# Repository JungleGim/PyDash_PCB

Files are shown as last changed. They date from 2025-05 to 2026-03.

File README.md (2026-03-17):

# PyDash_PCB - Information
This readme covers the printed circuit board or PCB portion of the PyDash. For the App design, Enclosure design, or OS design, see the below repositories:
- [PyDash_OS](https://github.com/JungleGim/PyDash_OS)
- [PyDash_App](https://github.com/JungleGim/PyDash_App)
- [PyDash_PCB](https://github.com/JungleGim/PyDash_PCB)
- [PyDash_Enclosure](https://github.com/JungleGim/PyDash_Enclosure)
- [PyDash_Builder](https://github.com/JungleGim/PyDash_Builder)

## Introduction
The PyDash_PCB is a daughter board that contains the hardware required for a rPi compute module (CM4) to function as a processor to display information on a 7in screen.

Additional details on the design considerations, required packages, and key features are included in the "Methodology" section of this readme.

# Project Status
## Revlog
- Rev 0: 06/02/2024
	- Initial issue
- Rev1a: 05/19/2025
	- Fixed button numbering to be appropriate when viewing the screen
- Rev2a: 02/15/2026
	- updates realted to Rev2.0a rebuild - includes new features and code architecture
	- Added micro SD socket for users to load dash config files
	- Updated USB port to USBC
	- Removed touch lines from screen and removed USB mux - no plans to utilize touch in future
	
## Future Development
The below is a list of wants/needs for future revisions; loosely listed in order of importance.

- Update mounting holes for CM4 to solder pads for use of solder-on standoffs to attach CM4
- Scope out board assembly cost

# Methodology
## History
TBD: quick detail starting with the arduino + daughter board on the 5in display as a proof of concept

## Key Considerations and Constraints
The following sections are some notes on the various considerations or any constraints when designing the display.

### Power Supply
As built, with the sourced display and components in the BOM, the display uses approximately 350-400mA when operation, at 100% backlight.

### Display
The chosen display is a 7inch 1024x600 IPS display sourced from waveshare [link](https://www.waveshare.com/70h-1024600.htm?sku=22671). The display is fastened to the carrier PCB via double-sided foam tape. The 40pin FPC jack directly connects to the HDMI output from the CM4.

To control the backlight via PWM, drive the "BL_en" pin high. The PWM signal is scaled from 1024 (100%) to 0 (0) for brightest to darkest.

Any HDMI compatable display should be able to be used with this design. While the FPC cable was a design choice, any other HDMI connection should be appropriate, depending on the chosen display.

Additional considerations for the HDMI hardware and driver configuration is contained in the "PyDash OS" readme.

#### PCB stackup
JLC PCB stackups for TDMS impedence considerations

* Chosen stackup: JLC04121H-3313 – 1oz (0.035mm) outer layer
	+ Chosen stackup option
	+ Top to inner 1 and inner 2 to bot separation is 0.1
	+ requires 0.18mm trace width for single-ended impedence target
	+ 0.3mm separation for differential impedence target

* Other available options with calculated requirements
	+ JLC04121H-7628 - 1oz (0.035mm) outer layer
		* Top to inner 1 and inner 2 to bot separation is 0.2
		* requires 0.3mm trace width for single-ended impedence target
		* 0.25mm separation for differential impedence target
	+ JLC04121H-1080 Stackup – 1oz (0.035mm) outer layer
		* Top to inner 1 and inner 2 to bot separation is 0.0764
		* requires 0.13mm width
		* 0.20mm separation for differential impedence target

# Known bugs and bug fixes
No current known bugs

# FAQ section
No current FAQ

# Copyright and licensing information
## GNU GPLv3
This program is free software: you can redistribute it and/or modify it under the terms of the GNU General Public License as published by the Free Software Foundation, either version 3 of the License, or (at your option) any later version.

This program is distributed in the hope that it will be useful, but WITHOUT ANY WARRANTY; without even the implied warranty of MERCHANTABILITY or FITNESS FOR A PARTICULAR PURPOSE.  See the
GNU General Public License for more details.

You should have received a copy of the GNU General Public License along with this program.  If not, see <https://www.gnu.org/licenses/>.

## Additional disclaimer
The information included is provided "as is", without warranty of any kind, express or implied, including but not limited to the warranties of merchantability, fitness for a particular purpose and non-infringement. In no event shall the authors or copyright holders be liable for any claim, damages or other liability, whether in an action of contract, tort or otherwise, arising from, out of or in connection with the software or the use or other dealings in the software or tools included in this repository.

# General Notes and References
While I am an engineer by trade, my area of focus is not computer architecture or system engineering. Likely some people have already looked at various aspects of the codebase and just shook their heads. That being said, I've compiled a list of considerations and notes for the project that have helped me along the way. These are listed below, in no particular order.

## References
Throughout the project, I have used many references, related to various aspects/items of the project. These are all compiled in the list below, in no particular order
- TBD any notable references

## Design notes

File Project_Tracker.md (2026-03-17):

# PyDash PCB - Project Tracker
project tracker for WIP issues, what's currently being worked on, and anything that may need to move to the actual README file

## Version
Version: 2.0a - TBD
Build Date: N/A

# WIP Version TODO list
* Test complete R2.0a assembly on bench with breakout board
* If successful, order/final assembly
	- Order PCB
	- Order Parts
	- Assemble

# Future Updates
Include any items below in the appropriate README.md file section
(none)

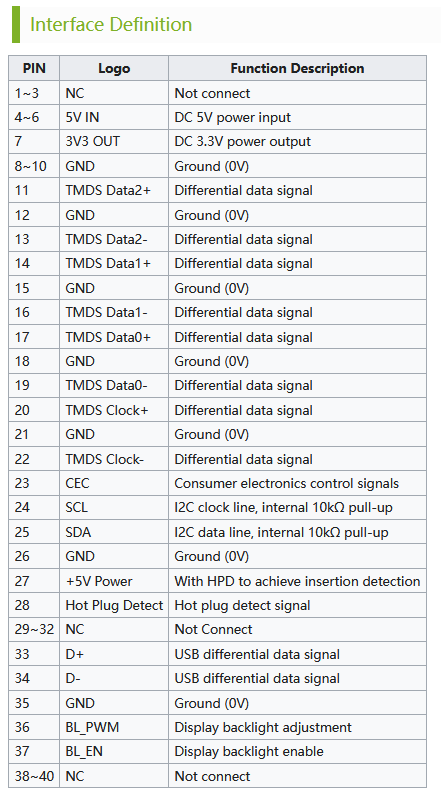
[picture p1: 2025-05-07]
design_and_ref_docs/waveshare_display/40pin_pinout.png

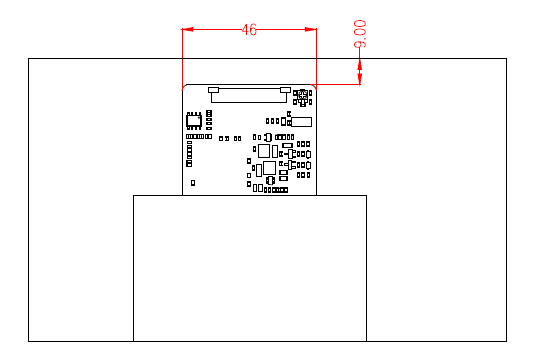
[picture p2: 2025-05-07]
design_and_ref_docs/waveshare_display/waveshare_display_back_dims.png

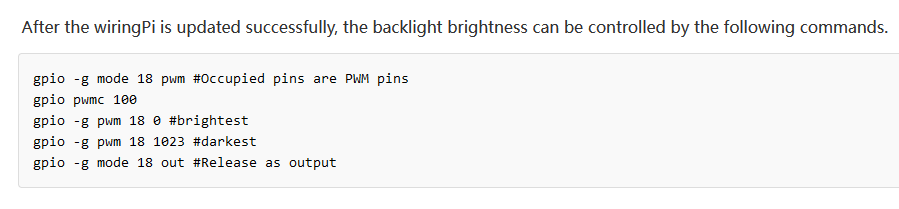
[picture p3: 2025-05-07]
design_and_ref_docs/waveshare_display/PWM_control.png

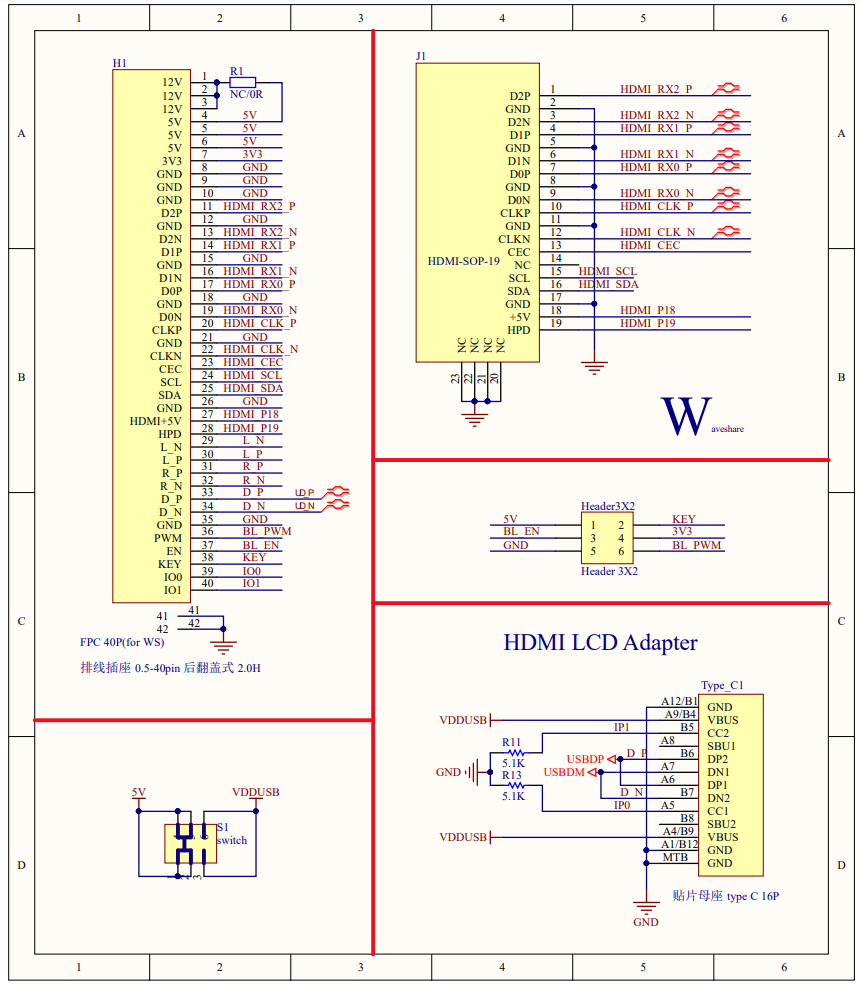
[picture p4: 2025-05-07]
design_and_ref_docs/waveshare_display/waveshare_40pin_hdmi_adapter_schema.png

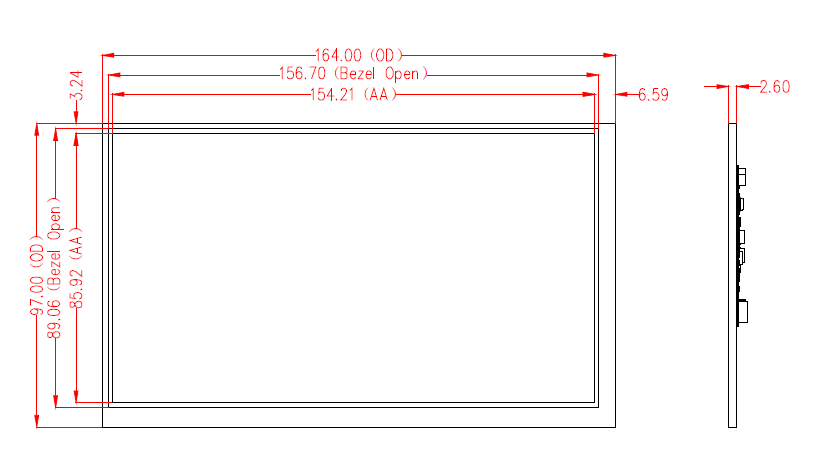
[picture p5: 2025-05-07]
design_and_ref_docs/waveshare_display/waveshare_display_dims.png

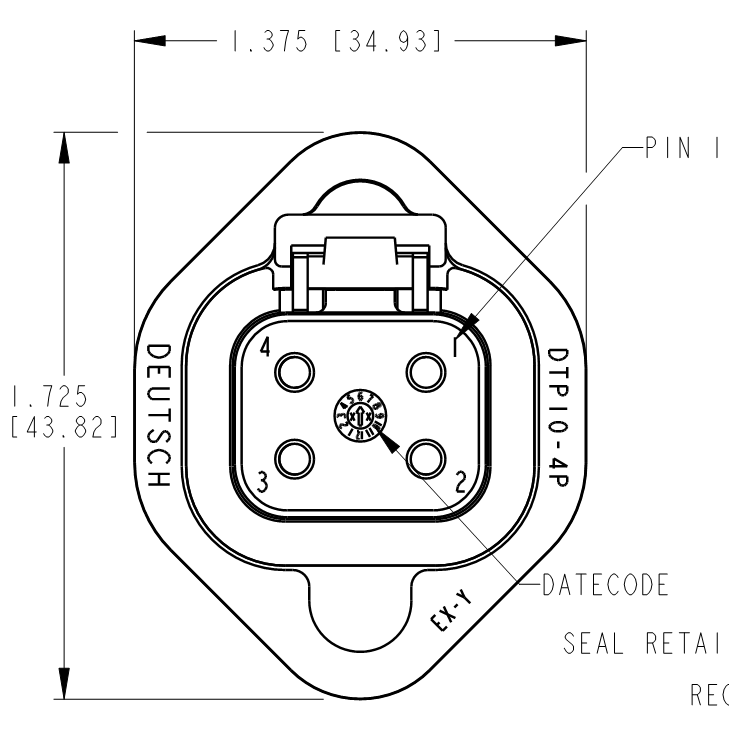
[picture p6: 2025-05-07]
design_and_ref_docs/dt10-40_top.png

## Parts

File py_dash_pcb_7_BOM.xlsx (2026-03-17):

 |  |  |  |  |  |  |  |  | BOM cost: | $158.13
Reference | Value | Footprint | Qty | Source/Reseller | Reseller_P/N | MFGR | MFGR_P/N | qty_check : 3/15/26 | price : 3/15/26 | Line_price
C1,C6,C19,C20,C26,C27,C28,C29,C30,C31 | 1u | Capacitor_SMD:C_0805_2012Metric | 10 | Mouser | 80-C0805C105M3R | Kemet | C0805C105M3RACTU | ok - 4k | $0.17 | $1.70
C18 | 100u | Capacitor_Tantalum_SMD:CP_EIA-3528-21_Kemet-B | 1 | Mouser | 581-TPSB107K010R0400 | Kyocera | TPSB107K010R0400 | ok - 10k | $0.90 | $0.90
C2,C5,C21,C22 | 10u_25v | Capacitor_Tantalum_SMD:CP_EIA-3528-21_Kemet-B | 4 | Mouser | 80-T495B106K25ATE750 | Kemet | T495B106K025ATE750 | ok - 5k | $1.50 | $6.00
C3,C4,C23,C25,C32 | 0u1 | Capacitor_SMD:C_0805_2012Metric | 5 | Mouser | 80-C0805C104M5R | Kemet | C0805C104M5RACTU | ok - 560k | $0.10 | $0.50
C33,C34 | 20p | Capacitor_SMD:C_0805_2012Metric | 2 | Mouser | 80-C0805C200F5G | Kemet | C0805C200F5GACTU | ok - 5k | $1.17 | $2.34
C7 | 1n2 | Capacitor_SMD:C_0805_2012Metric | 1 | Mouser | 80-C0805C122K5R | Kemet | C0805C122K5RACTU | ok - 8k | $0.19 | $0.19
C8,C9,C10,C11,C12,C13,C14,C15,C16,C17,C24 | 10u | Capacitor_SMD:C_0805_2012Metric | 11 | Mouser | 80-C0805C106K4PAC | Kemet | C0805C106K4PAC | ok - 17k | $0.17 | $1.87
D1,D6,D7,D8 | red | LED_SMD:LED_0805_2012Metric | 4 | Mouser | 710-150080RS75000 | Wurth | 150080RS75000 | ok - 65k | $0.19 | $0.76
D2,D3,D4,D5 | 27V | Diode_SMD:D_SOD-123 | 4 | Mouser | 863-MMSZ27T1G | OnSemi | MMSZ27T1G | ok - 23k | $0.12 | $0.48
D9 | NUP2105L | Package_TO_SOT_SMD:SOT-23 | 1 | Mouser | 863-NUP2105LT1G | OnSemi | NUP2105LT1G | ok - 91k | $0.34 | $0.34
H2,H4,H7,He1 | CM4_M2_1.5ET | MountingHole:MountingHole_3.2mm_M3_DIN965_Pad_TopOnly | 4 | Mouser | 710-9774015243R | Wurth | 9774015243R | ok - 20k | $1.16 | $4.64
H8,H9,H10,H11,H12,H13,H14,H15,H16,H17,H18,H19,H20,H21,H22,H23 | Standoff_M2.5_6ET | user:Standoff_M2.5_6ET | 16 | Mouser | 153-SMTSO-M25-6ET | PEM | SMTSO-M25-6ET | ok - 8k | $1.24 | $19.84
J1 | Micro_SD_Card_Det1 | Connector_Card:microSD_HC_Hirose_DM3AT-SF-PEJM5 | 1 | Mouser | 798-DM3ATSFPEJM541 | Hirose | DM3AT-SF-PEJM5(41) | ok - 18k | $3.38 | $3.38
J2 | FFC2B28-40-G | user:GCT_FFC2B28-40-G | 1 | Mouser | 640-FFC2B28-40-G | GCT | FFC2B28-40-G | ok - 6k | $1.00 | $1.00
J3 | USB_C_Receptacle_USB2.0_14P | Connector_USB:USB_C_Receptacle_GCT_USB4115-03-C | 1 | Mouser | 640-USB4115-03-C | GCT | USB4115-03-C | ok - 27k | $1.13 | $1.13
J4 | CANbus | user:DT13-4P | 1 | Mouser | 571-DTP10-4P | Deutsch | DTP10-4P | ok - 120 | $18.35 | $18.35
J5 | CM4-A | N/A | 1 | Mouser | 798-DF40C100DS0.4V51 | Hirose | DF40C-100DS-0.4V(51) | ok - 37k | $1.76 | $1.76
J6 | CM4-B | N/A | 1 | Mouser | 798-DF40C100DS0.4V51 | Hirose | DF40C-100DS-0.4V(51) | ok - 37k | $1.76 | $1.76
J7 | HDMI_ribbon | N/A | 1 | Mouser | 640-0540D0152A4064G | GCT | 05-40-D-0152-A-4-06-4-G | ok - 500 | $2.10 | $2.10
J8 | HDMI_Display | N/A | 1 | Waveshare | 70H-1024600-IPS-A | Waveshare | 70H-1024600-IPS-A | ok | $30.00 | $30.00
J9, J10, J11, J12, J13, J14, J15 | 12x12 keycap - white |  | 6 | Mouser | 653-B32-1360 | Omron | B32-1360 | ok - 5k | $0.20 | $1.20
L1 | 3h3 | Inductor_SMD:L_Bourns_SRN6045TA | 1 | Mouser | 652-SRN6045-3R3Y | Bourns | SRN6045-3R3Y | ok - 20k | $0.42 | $0.42
Q1,Q2,Q3 | DMG2307 | Package_TO_SOT_SMD:SOT-23 | 3 | Mouser | 621-DMG2307L-7 | Diodes | DMG2307L-7 | ok - 53k | $0.42 | $1.26
R1,R12 | 660r | Resistor_SMD:R_0805_2012Metric | 2 | Mouser | 71-CRCW0805-665-E3 | Vishay | CRCW0805665RFKEA | ok - 102k | $0.10 | $0.20
R10 | 2k7 | Resistor_SMD:R_0805_2012Metric | 1 | Mouser | 71-CRCW0805-2.7K-E3 | Vishay | CRCW08052K70FKEA | ok - 25k | $0.19 | $0.19
R11 | 1k | Resistor_SMD:R_0805_2012Metric | 1 | Mouser | 71-CRCW0805-1.0K-E3 | Vishay | CRCW08051K00FKEA | ok - 604k | $0.10 | $0.10
R15,R16,R19,R20,R24,R25 | 27k | Resistor_SMD:R_0805_2012Metric | 6 | Mouser | 71-CRCW0805-27K-E3 | Vishay | CRCW080527K0FKEA | ok - 52k | $0.12 | $0.72
R2 | 10r | Resistor_SMD:R_0805_2012Metric | 1 | Mouser | 71-CRCW0805-10-E3 | Vishay | CRCW080510R0FKEA | ok - 176k | $0.10 | $0.10
R26 | 4k7 | Resistor_SMD:R_0805_2012Metric | 1 | Mouser | 71-CRCW0805-4.7K-E3 | Vishay | CRCW08054K70FKEA | ok - 224k | $0.10 | $0.10
R3 | 12k 1% | Resistor_SMD:R_0805_2012Metric | 1 | Mouser | 71-CRCW0805-12K | Vishay | CRCW080512K0FKTA | ok - 7k | $0.15 | $0.15
R4,R7,R8,R9,R13,R14,R17,R18,R21,R22,R23 | 10k | Resistor_SMD:R_0805_2012Metric | 11 | Mouser | 71-CRCW0805-10K-E3 | Vishay | CRCW080510K0FKEA | ok - 685k | $0.10 | $1.10
R5 | 20k 1% | Resistor_SMD:R_0805_2012Metric | 1 | Mouser | 71-CRCW0805-20K-E3 | Vishay | CRCW080520K0FKEA | ok - 17 | $0.10 | $0.10
R6 | 2k2 1% | Resistor_SMD:R_0805_2012Metric | 1 | Mouser | 71-CRCW0805-2.2K-E3 | Vishay | CRCW08052K20FKEA | ok - 90k | $0.12 | $0.12
SW1 | nBoot | Button_Switch_SMD:SW_DIP_SPSTx01_Slide_6.7x4.1mm_W8.61mm_P2.54mm_LowProfile | 1 | Mouser | 774-219G-2ESF | CTS | 219G-2ESF | ok - 2k | $0.86 | $0.86
SW2,SW3,SW4,SW5,SW6,SW7 | SW_Push | user:SW_B3F-4050_OMR | 6 | Mouser | 653-B3F-5050 | Omron | B3F-5050 | ok - 6k | $0.34 | $2.04
U1 | CM4102008 | user:MODULE_CM4102008 | 1 | Digikey | 2648-SC0696-ND | Raspberry PI | CM4001008 | ok - 400 | $35.00 | $35.00
U2 | AP64501SP-13 | user:SOIC127P600X170-9N | 1 | Mouser | 621-AP64501SP-13 | Diodes | AP64501SP-13 | ok - 15k | $2.09 | $2.09
U3 | BD33FC0FP | Package_TO_SOT_SMD:TO-252-2 | 1 | Mouser | 863-NCV1117DT33T5G | OnSemi | NCV1117DT33T5G | ok - 13k | $0.60 | $0.60
U4 | EMIF06-MSD02N16 | user:EMIF06MSD02N16 | 1 | Mouser | 511-EMIF06-MSD02N16 | ST | EMIF06-MSD02N16 | ok - 7k | $1.03 | $1.03
U5,U6 | TPD8S009DSMR | user:IC_TPD8S009DSMR | 2 | Mouser | 595-TPD8S009DSMR | TI | TPD8S009DSMR | ok - 950 | $1.82 | $3.64
U7 | TPD2EUSB30 | Package_TO_SOT_SMD:Texas_DRT-3 | 1 | Mouser | 595-TPD2E009DRTR | TI | TPD2E009DRTR | ok - 4k | $0.81 | $0.81
U8 | MCP2515-xST | Package_SO:TSSOP-20_4.4x6.5mm_P0.65mm | 1 | Mouser | 579-MCP2515T-E/ST | Microchip | MCP2515T-E/ST | ok - 2k | $3.05 | $3.05
U9 | SN65HVD234 | Package_SO:SOIC-8_3.9x4.9mm_P1.27mm | 1 | Mouser | 595-SN65HVD234DR | TI | SN65HVD234DR | ok - 78k | $3.12 | $3.12
Y1 | 16Mhz | Crystal:Crystal_SMD_3225-4Pin_3.2x2.5mm | 1 | Mouser | 732-FA-23816B-C3 | Epson | FA-238 16.0000MB-C3 | ok - 39k | $1.09 | $1.09

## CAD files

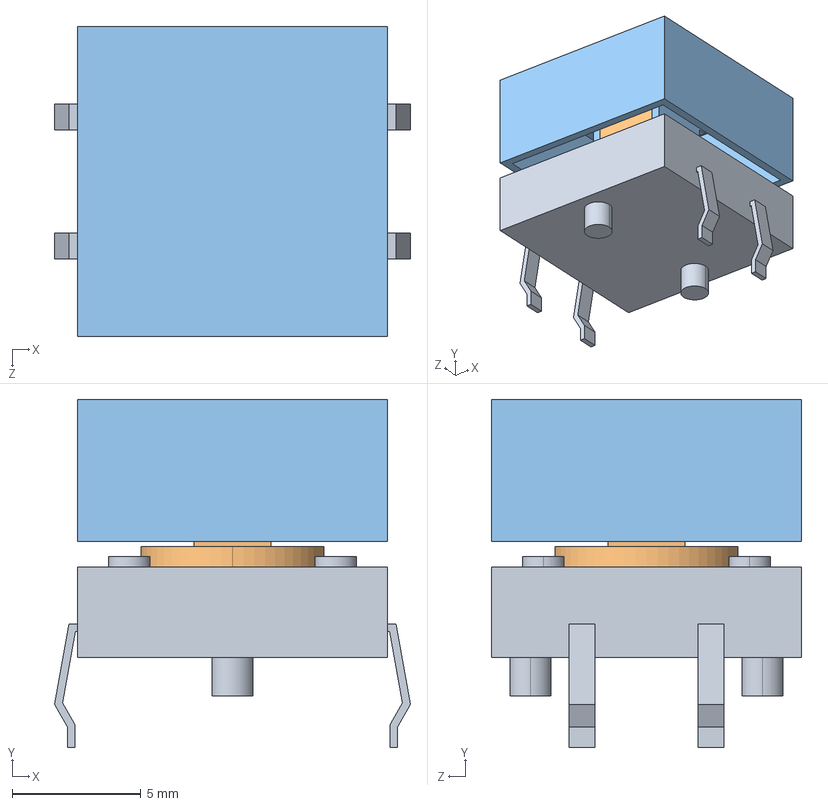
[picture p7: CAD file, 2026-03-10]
PCB_files/user_lib/B3F_5050/B3F-5050_12mm_keycap.STEP
13.8 x 13.5 x 12.0 mm
B3F_5050_BASE_3_B3F_5050_BASE_3
B3F_5050_BUTTON_3_B3F_5050_BUTTON_3
12mm_keycap

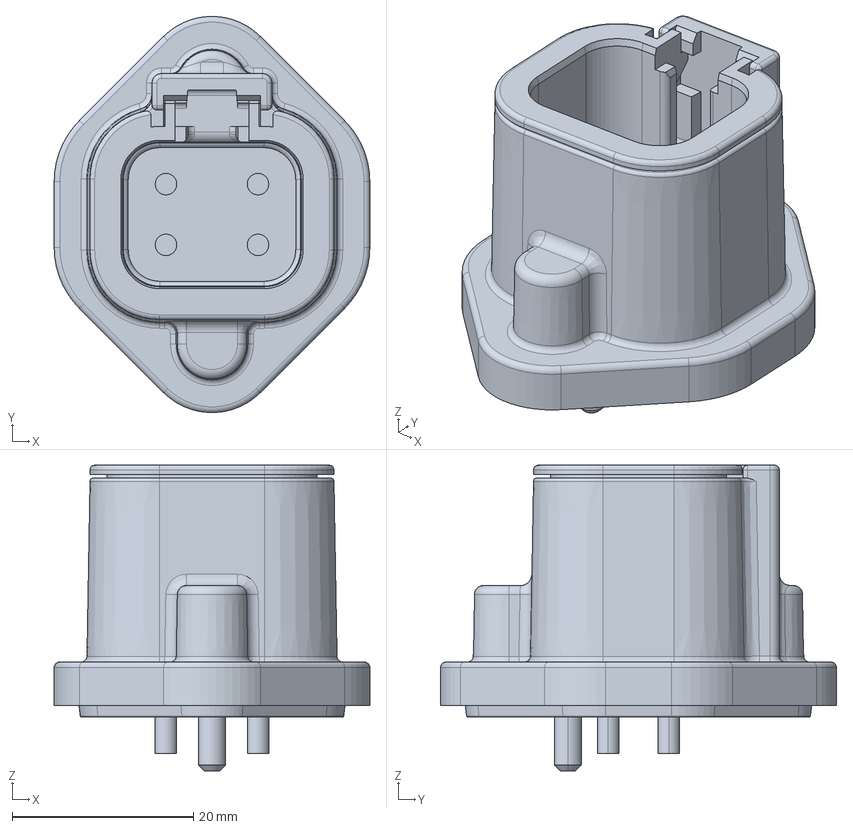
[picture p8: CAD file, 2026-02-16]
PCB_files/user_lib/dt13-4p/c-dtp10-4p-b-3d.stp
34.8 x 43.7 x 33.7 mm

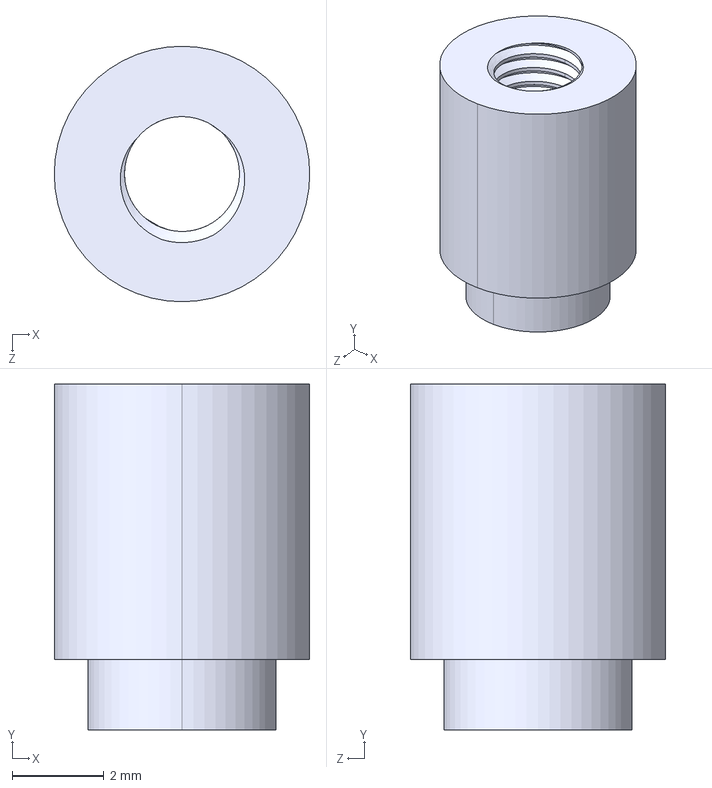
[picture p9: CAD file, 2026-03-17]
PCB_files/user_lib/M2.5_6mm_standoff.STEP
5.56 x 7.53 x 5.56 mm

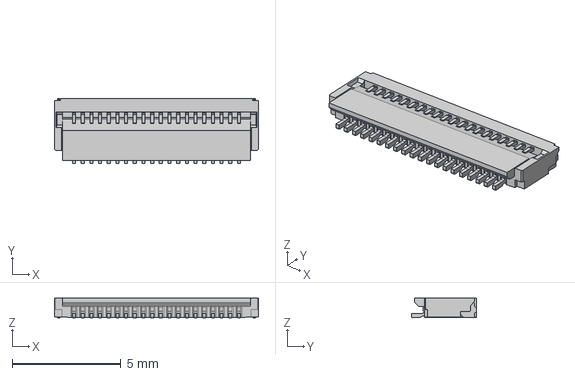
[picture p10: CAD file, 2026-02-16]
PCB_files/user_lib/TF13BSA-20S-0.4SH_800_/TF13BSA-20S-0.4SH_800_.step
9.40 x 3.00 x 0.9 mm

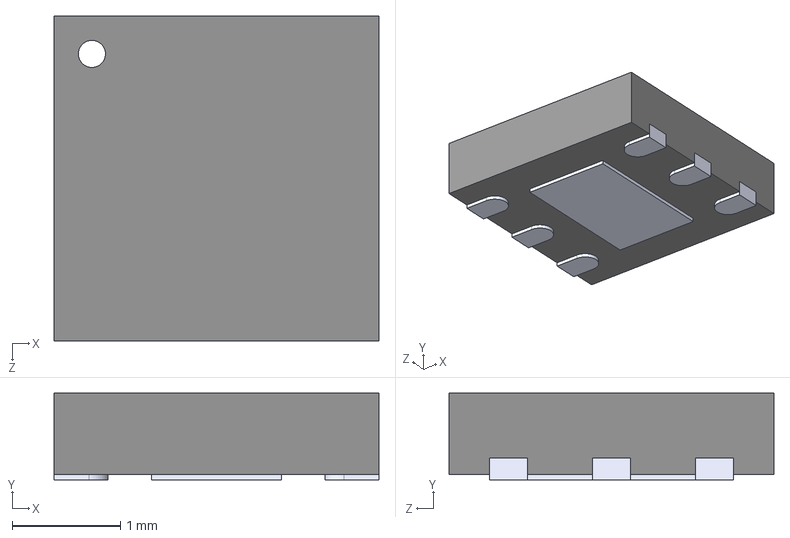
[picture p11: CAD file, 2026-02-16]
PCB_files/user_lib/TPD4E001DRSR_/TPD4E001DRSR..step
3.00 x 0.8 x 3.00 mm

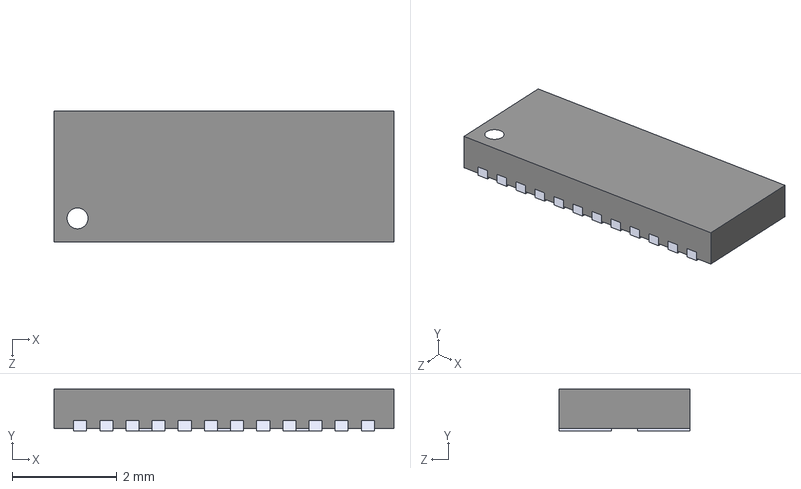
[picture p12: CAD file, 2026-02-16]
PCB_files/user_lib/TPD8S009DSMR/TPD8S009DSMR.step
6.50 x 0.8 x 2.50 mm

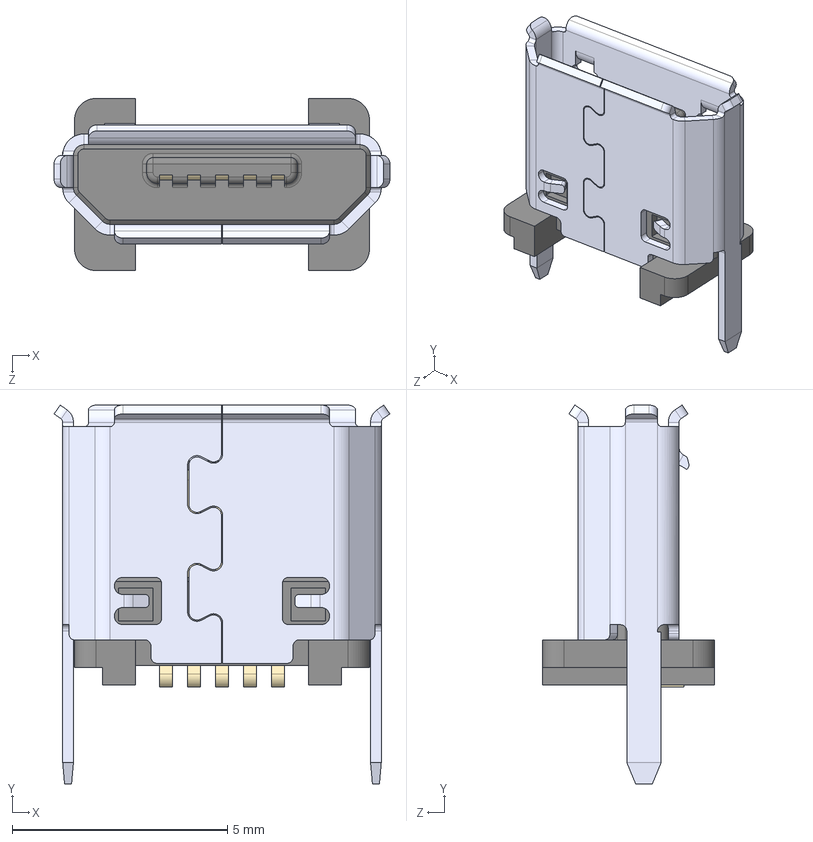
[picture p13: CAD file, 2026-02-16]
PCB_files/user_lib/USB3140-30-0170-1-C_REVE1/USB3140-30-0230-1-C--3DModel-STEP-56544.STEP
7.80 x 8.80 x 4.00 mm

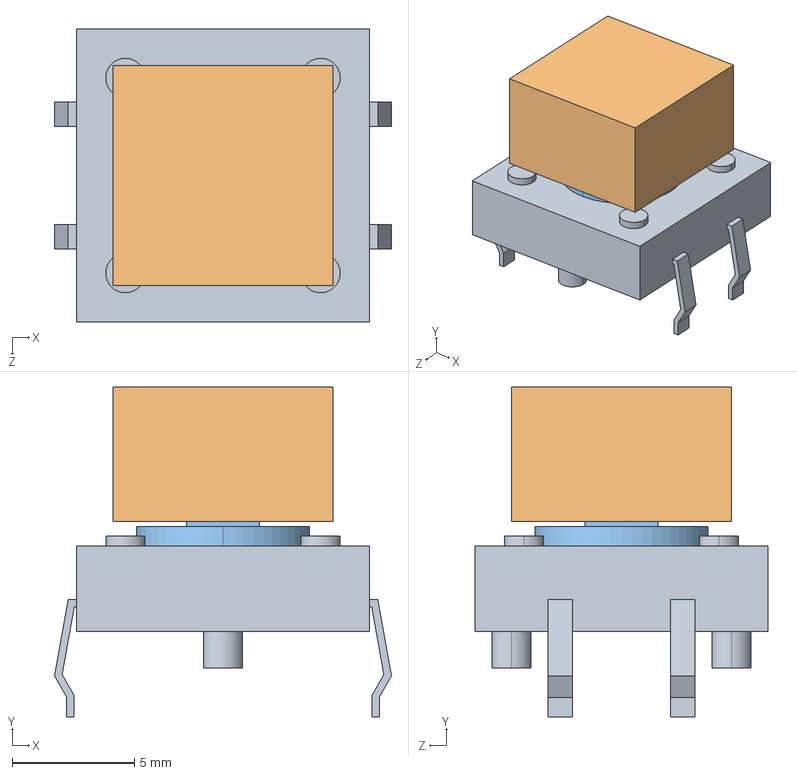
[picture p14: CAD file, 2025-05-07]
PCB_files/user_lib/B3F_5050/B3F-5050.STEP
13.8 x 13.5 x 12.0 mm
B3F_5050_BASE
B32_1200
B3F_5050_BUTTON

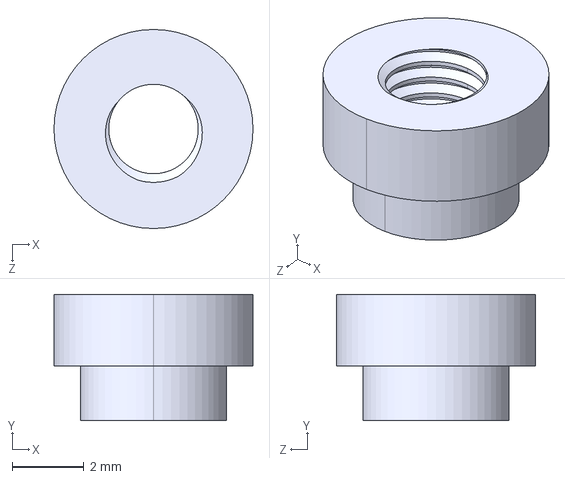
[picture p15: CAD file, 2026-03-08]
PCB_files/user_lib/M2.5_2mm_standoff.STEP
5.56 x 3.53 x 5.56 mm

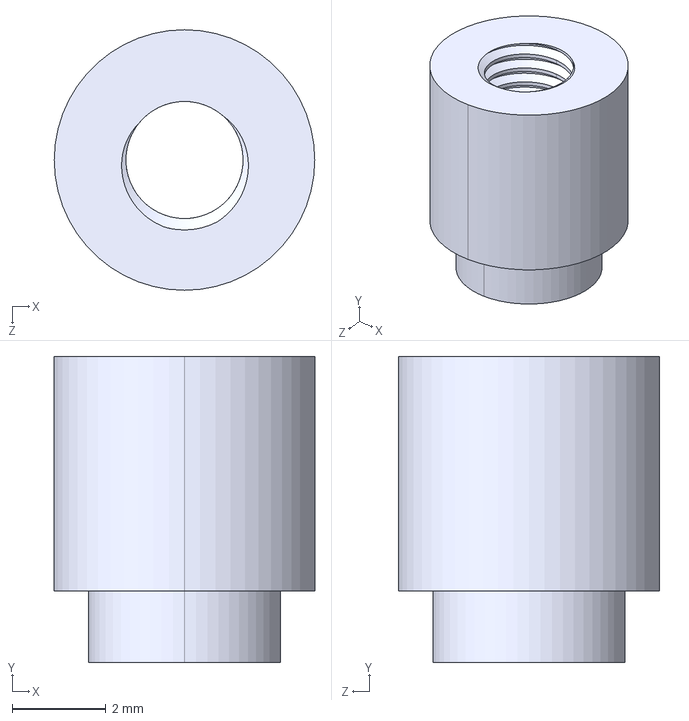
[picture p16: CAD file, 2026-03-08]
PCB_files/user_lib/M2.5_5mm_standoff.STEP
5.56 x 6.53 x 5.56 mm

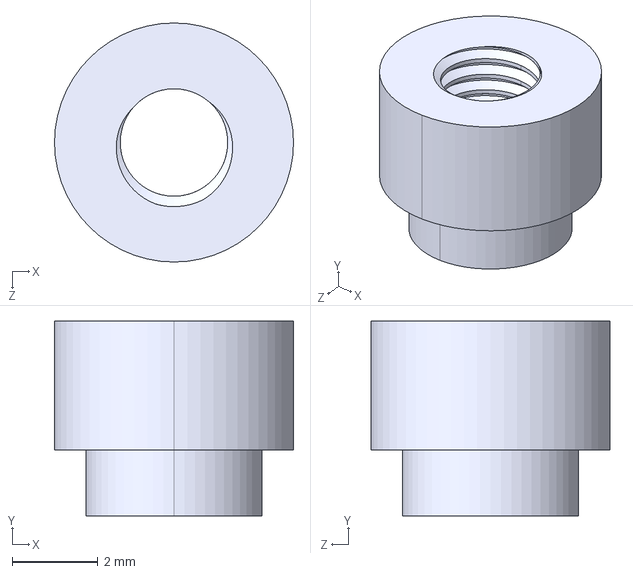
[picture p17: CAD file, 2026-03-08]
PCB_files/user_lib/M2.5_3mm_standoff.STEP
5.56 x 4.53 x 5.56 mm

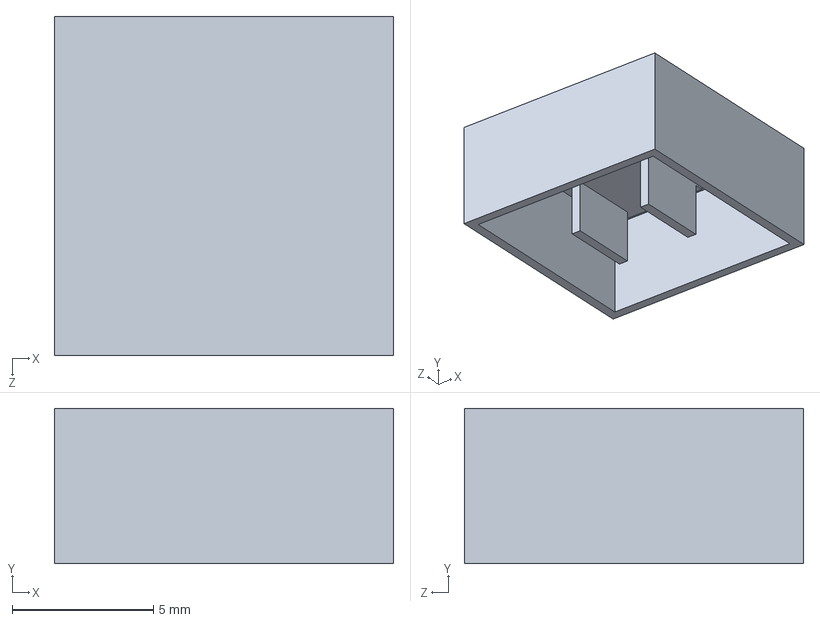
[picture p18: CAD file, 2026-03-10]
PCB_files/user_lib/B3F_5050/B3F-5050_12mm_keycap_solidworks_assy/12mm_keycap.SLDPRT
12.0 x 5.50 x 12.0 mm

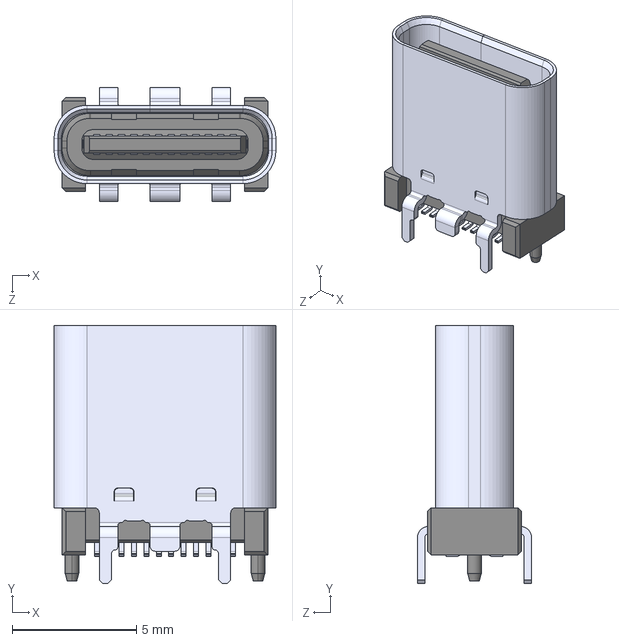
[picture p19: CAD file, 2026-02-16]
PCB_files/user_lib/USB4115-03-C--3DModel-STEP-56544.STEP
8.94 x 10.4 x 4.60 mm

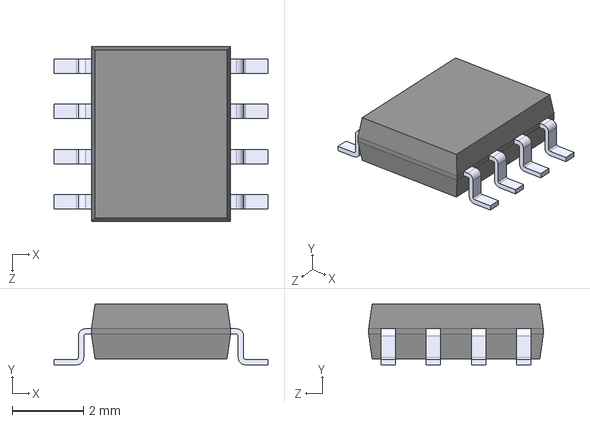
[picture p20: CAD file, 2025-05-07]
PCB_files/user_lib/AP64501SP-13/AP64501SP-13.step
6.00 x 1.70 x 4.90 mm

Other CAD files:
PCB_files/user_lib/B3F_5050/B3F-5050_12mm_keycap_solidworks_assy/B3F-5050.SLDASM
PCB_files/user_lib/B3F_5050/B3F-5050_12mm_keycap_solidworks_assy/B3F_5050_BASE_3.SLDPRT
PCB_files/user_lib/B3F_5050/B3F-5050_12mm_keycap_solidworks_assy/B3F_5050_BUTTON_3.SLDPRT
PCB_files/user_lib/CSD23280F3/CSD23280F3.step
PCB_files/user_lib/1050570001.stp
PCB_files/user_lib/B3F_5050/B3F-5050_12mm_keycap_solidworks_assy/B3F-5050(2).SLDASM
PCB_files/user_lib/LM66100DCKR/LM66100DCKR.step
PCB_files/user_lib/M2.5_5mm_standoff.SLDPRT

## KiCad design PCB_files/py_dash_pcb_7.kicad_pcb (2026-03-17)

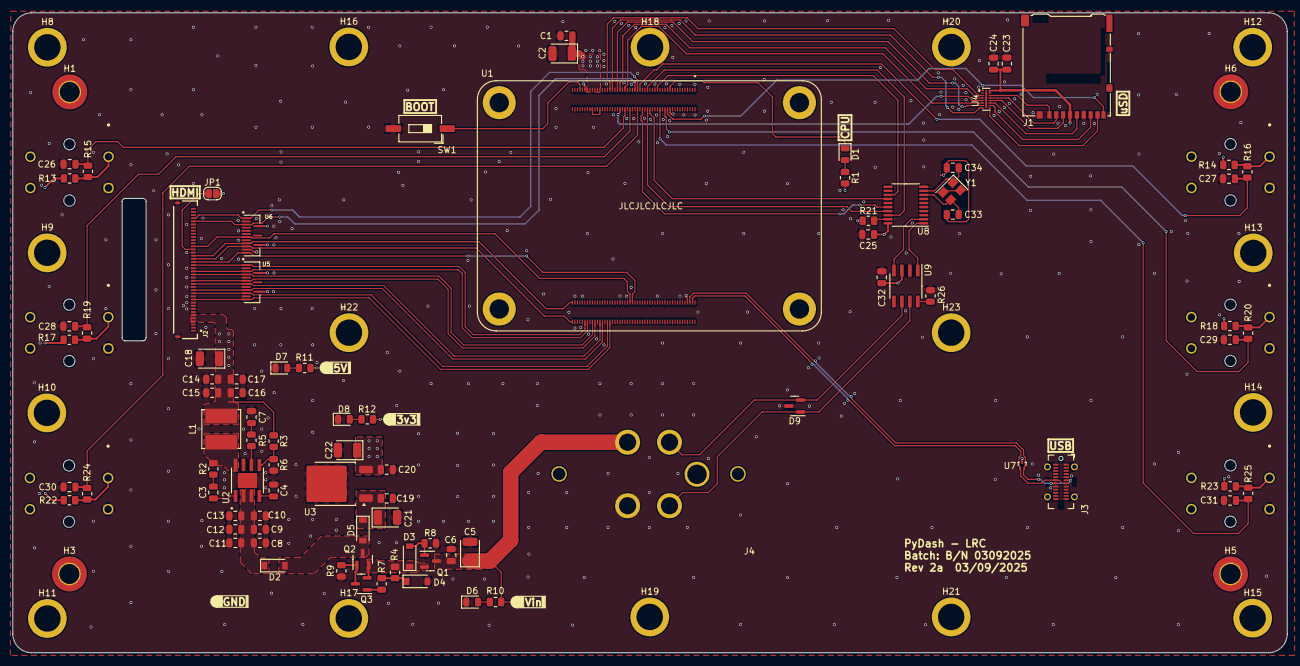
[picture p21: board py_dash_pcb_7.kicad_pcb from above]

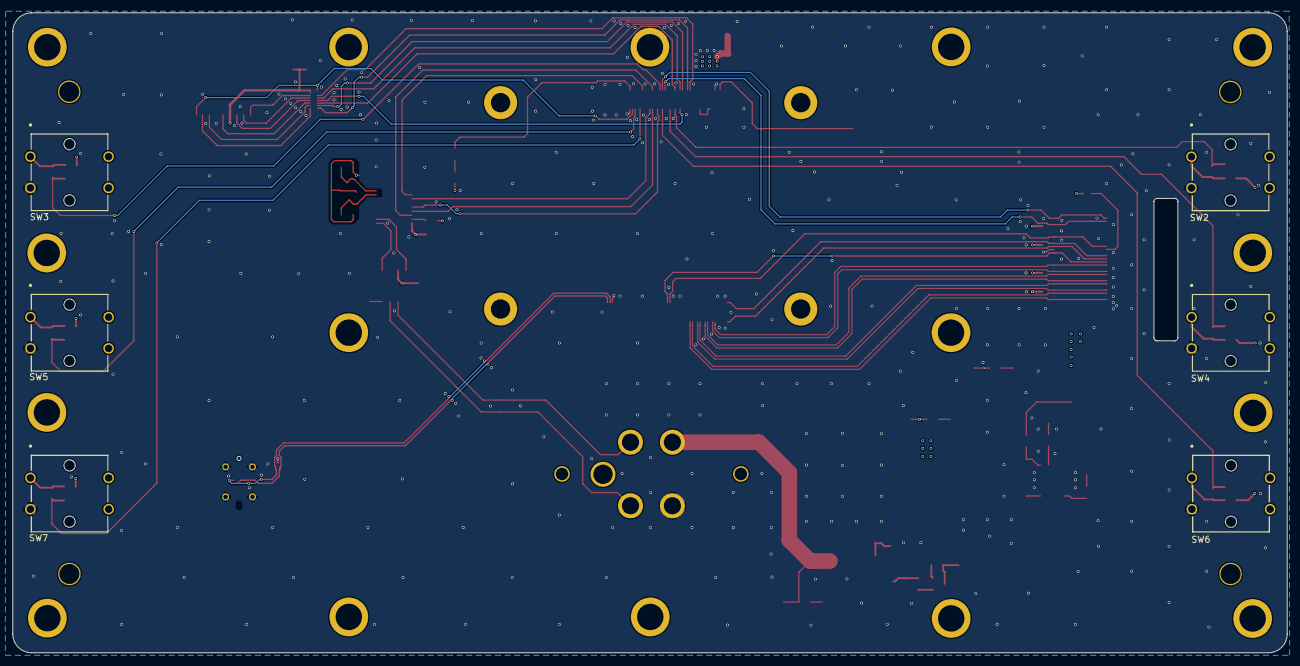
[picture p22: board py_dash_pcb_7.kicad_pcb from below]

Board: 4 copper layers, 203.8 x 102.3 mm, 120 parts (6 on the bottom side), 82 nets.

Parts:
C1, C6, C19, C20, C26, C27, C28, C29, C30, C31: 1u; C_0805_2012Metric
C2, C5, C21, C22: 10u_25v; CP_EIA-3528-21_Kemet-B
C3, C4, C23, C25, C32: 0u1; C_0805_2012Metric
C7: 1n2; C_0805_2012Metric
C8, C9, C10, C11, C12, C13, C14, C15, C16, C17, C24: 10u; C_0805_2012Metric
C18: 100u; CP_EIA-3528-21_Kemet-B
C33, C34: 20p; C_0805_2012Metric
D1, D6, D7, D8: red; LED_0805_2012Metric
D2, D3, D4, D5: 27V; D_SOD-123
D9: NUP2105L; SOT-23
H1, H3, H5, H6: MountingHole_M2; MountingHole_3.2mm_M3_DIN965_Pad_TopOnly
H8, H9, H10, H11, H12, H13, H14, H15, H16, H17, H18, H19, H20, H21, H22, H23: Standoff_M2.5_6ET
J1: Micro_SD_Card_Det1; microSD_HC_Hirose_DM3AT-SF-PEJM5
J2: FFC2B28-40-G; GCT_FFC2B28-40-G
J3: USB_C_Receptacle_USB2.0_14P; USB_C_Receptacle_GCT_USB4115-03-C
J4: CANbus; DT13-4P
JP1: p18_jmp; SolderJumper-2_P1.3mm_Open_RoundedPad1.0x1.5mm
L1: 3h3; L_Bourns_SRN6045TA
NT1: NetTie_2; NetTie-2_SMD_Pad0.2mm
Q1, Q2, Q3: DMG2307; SOT-23
R1, R12: 660r; R_0805_2012Metric
R2: 10r; R_0805_2012Metric
R3: 12k 1%; R_0805_2012Metric
R4, R7, R8, R9, R13, R14, R17, R18, R21, R22, R23: 10k; R_0805_2012Metric
R5: 20k 1%; R_0805_2012Metric
R6: 2k2 1%; R_0805_2012Metric
R10: 2k7; R_0805_2012Metric
R11: 1k; R_0805_2012Metric
R15, R16, R19, R20, R24, R25: 27k; R_0805_2012Metric
R26: 4k7; R_0805_2012Metric
SW1: nBoot; SW_DIP_SPSTx01_Slide_6.7x4.1mm_W8.61mm_P2.54mm_LowProfile
SW2, SW3, SW4, SW5, SW6, SW7: SW_Push; SW_B3F-4050_OMR
TP1: TP_3v3; TestPoint_Pad_D1.0mm
TP2: TP_5V; TestPoint_Pad_D1.0mm
TP3: TP_12V; TestPoint_Pad_D1.0mm
TP4: TP_GND; TestPoint_Pad_D1.0mm
U1: CM4102008; MODULE_CM4102008
U2: AP64501SP-13; SOIC127P600X170-9N
U3: BD33FC0FP; TO-252-2
U4: EMIF06-MSD02N16; EMIF06MSD02N16
U5, U6: TPD8S009DSMR; IC_TPD8S009DSMR
U7: TPD2EUSB30; Texas_DRT-3
U8: MCP2515-xST; TSSOP-20_4.4x6.5mm_P0.65mm
U9: SN65HVD234; SOIC-8_3.9x4.9mm_P1.27mm
Y1: 16Mhz; Crystal_SMD_3225-4Pin_3.2x2.5mm

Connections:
+3.3V: C20.1, C22.1, C23.1, C24.2, C25.2, C32.1, J1.4 (VDD), R1.2, R12.2, R13.1, R14.1, R17.1, R18.1, R21.1, R22.1, R23.1, TP1.1, U3.3 (VO), U4.15 (VCC), U4.16 (RDATA_VCC), U5.13 (VCC), U5.15 (VCC), U6.13 (VCC), U6.15 (VCC), U8.20 (VDD), U9.3 (VCC)
+5V: C1.1, C2.1, C14.2, C15.2, C16.2, C17.2, C18.1, J2.35, J2.36, J2.37, JP1.2 (B), L1.2, R3.1, R11.2, TP2.1, U1.77 (+5V(INPUT)), U1.79 (+5V(INPUT)), U1.81 (+5V(INPUT)), U1.83 (+5V(INPUT)), U1.85 (+5V(INPUT)), U1.87 (+5V(INPUT))
+12V: C5.1, C6.1, J4.1, Q1.3 (D), R10.2, TP3.1
/power/3v3_in: C19.1, C21.1, D5.1 (K), U3.1 (VCC)
/power/5v_Vin: C8.2, C9.2, C10.2, C11.2, C12.2, C13.2, D2.1 (K), U2.2 (VIN), U2.3 (EN)
/power/Vprot: D2.2 (A), D5.2 (A), Q2.3 (D)
CAN_H: D9.1 (K), J4.3, U9.7 (CANH)
CAN_INT: U1.31 (GPIO12), U8.13 (~INT)
CAN_L: D9.2 (K), J4.2, U9.6 (CANL)
CEC: J2.18, U1.151 (HDMI0_CEC), U6.12 (D3-)
CK+: J2.21, U1.188 (HDMI0_CLK_P), U5.3 (D0-)
CK-: J2.19, U1.190 (HDMI0_CLK_N), U5.1 (D0+)
D0+: J2.24, U1.182 (HDMI0_TX0_P), U5.6 (D1-)
D0-: J2.22, U1.184 (HDMI0_TX0_N), U5.4 (D1+)
D1+: J2.27, U1.176 (HDMI0_TX1_P), U5.9 (D2-)
D1-: J2.25, U1.178 (HDMI0_TX1_N), U5.7 (D2+)
D2+: J2.30, U1.170 (HDMI0_TX2_P), U5.12 (D3-)
D2-: J2.28, U1.172 (HDMI0_TX2_N), U5.10 (D3+)
GND: C1.2, C2.2, C4.1, C5.2, C6.2, C7.1, C8.1, C9.1, C10.1, C11.1, C12.1, C13.1, C14.1, C15.1, C16.1, C17.1, C18.2, C19.2, C20.2, C21.2, C22.2, C23.2, C24.1, C25.1, C26.2, C27.2, C28.2, C29.2, C30.2, C31.2, C32.2, D4.2 (A), D6.1 (K), D7.1 (K), D8.1 (K), D9.3 (A), J1.6 (VSS), J1.10 (SHIELD), J2.6, J2.15, J2.20, J2.23, J2.26, J2.29, J2.31, J2.32, J2.33, J2.S1 (SHIELD), J2.S2 (SHIELD), J3.A1 (GND), J3.A5 (CC1), J3.A12 (GND), J3.B1 (GND), J3.B5 (CC2), J3.B12 (GND), J3.S1 (SHIELD), J4.4, NT1.1, R6.2, R8.2, R9.2, R26.2, SW1.2, SW2.3 (2), SW3.3 (2), SW4.3 (2), SW5.3 (2), SW6.3 (2), SW7.3 (2), TP4.1, U1.1 (GND), U1.2 (GND), U1.7 (GND), U1.8 (GND), U1.13 (GND), U1.14 (GND), U1.22 (GND), U1.23 (GND), U1.32 (GND), U1.33 (GND), U1.42 (GND), U1.43 (GND), U1.52 (GND), U1.53 (GND), U1.59 (GND), U1.60 (GND), U1.65 (GND), U1.66 (GND), U1.71 (GND), U1.74 (GND), U1.89 (WL_~DISABLE), U1.91 (BT_~DISABLE), U1.98 (GND), U1.101 (USB_OTG_ID), U1.107 (GND), U1.108 (GND), U1.113 (GND), U1.114 (GND), U1.119 (GND), U1.120 (GND), U1.125 (GND), U1.126 (GND), U1.131 (GND), U1.132 (GND), U1.137 (GND), U1.138 (GND), U1.144 (GND), U1.150 (GND), U1.155 (GND), U1.156 (GND), U1.161 (GND), U1.162 (GND), U1.167 (GND), U1.168 (GND), U1.173 (GND), U1.174 (GND), U1.179 (GND), U1.180 (GND), U1.185 (GND), U1.186 (GND), U1.191 (GND), U1.192 (GND), U1.197 (GND), U1.198 (GND), U2.7 (GND), U2.9 (EP), U3.2 (GND), U4.17 (EP_(GND)), U5.2 (GND), U5.5 (GND), U5.8 (GND), U5.11 (GND), U6.2 (GND), U6.5 (GND), U6.8 (GND), U6.11 (GND), U7.3 (GND), U8.10 (VSS), U9.2 (GND)
HPD: J2.13, U1.153 (HDMI0_HOTPLUG), U6.7 (D2+)
unnamed: C3.2, R2.1
unnamed: C7.2, R5.1
unnamed: D1.2 (A), R1.1
unnamed: D1.1 (K), U1.21 (PI_~LED_ACTIVITY)
unnamed: D3.2 (A), Q1.1 (G), R8.1
unnamed: D3.1 (K), Q1.2 (S), Q2.2 (S), Q3.2 (S), R4.1
unnamed: D4.1 (K), R4.2, R7.2
unnamed: D6.2 (A), R10.1
unnamed: D7.2 (A), R11.1
unnamed: D8.2 (A), R12.1
unnamed: J1.5 (CLK), U4.11 (CLK_EX)
unnamed: J1.3 (CMD), U4.12 (CMD_EX)
unnamed: J1.7 (DAT0), U4.10 (DAT0_EX)
unnamed: J1.8 (DAT1), U4.9 (DAT1_EX)
unnamed: J1.1 (DAT2), U4.14 (DAT2_EX)
unnamed: J1.2 (DAT3/CD), U4.13 (DAT3_EX)
unnamed: J2.14, JP1.1 (A)
unnamed: Q2.1 (G), Q3.3 (D), R9.1
unnamed: Q3.1 (G), R7.1
unnamed: R13.2, R15.2, SW2.1
unnamed: R14.2, R16.2, SW3.1
unnamed: R17.2, R19.2, SW4.1
unnamed: R18.2, R20.2, SW5.1
unnamed: R22.2, R24.2, SW6.1
unnamed: R23.2, R25.2, SW7.1
unnamed: U1.78 (GPIO_VREF), U1.84 (CM4_3.3V(OUTPUT)), U1.86 (CM4_3.3V(OUTPUT))
unnamed: C3.1, U2.1 (BST)
unnamed: R5.2, U2.6 (COMP)
unnamed: R3.2, R6.1, U2.5 (FB)
unnamed: C4.2, U2.4 (SS)
unnamed: L1.1, R2.2, U2.8 (SW)
unnamed: R21.2, U8.19 (~RESET)
unnamed: R26.1, U9.8 (Rs)
OSC3: C34.2, U8.9 (OSC1), Y1.1
OSC4: C33.2, U8.8 (OSC2), Y1.3
OSC_GND: C33.1, C34.1, NT1.2, Y1.2, Y1.4
RX_can: U8.2 (RXCAN), U9.4 (R)
SCL: J2.17, U1.200 (HDMI0_SCL), U6.10 (D3+)
SDA: J2.16, U1.199 (HDMI0_SDA), U6.9 (D2-)
SD_CLK: U1.57 (SD_CLK), U4.6 (CLK_IN)
SD_CMD: U1.62 (SD_CMD), U4.5 (CMD_IN)
SD_DAT0: U1.63 (SD_DAT0), U4.7 (DAT0_IN)
SD_DAT1: U1.67 (SD_DAT1), U4.8 (DAT1_IN)
SD_DAT2: U1.69 (SD_DAT2), U4.3 (DAT2_IN)
SD_DAT3: U1.61 (SD_DAT3), U4.4 (DAT3_IN)
SD_DET: J1.9 (DET), U1.24 (GPIO26), U4.1 (WP/CD)
SPI0_CE0: U1.39 (GPIO8), U8.18 (~CS)
SPI0_MISO: U1.40 (GPIO9), U8.17 (SO)
SPI0_MOSI: U1.44 (GPIO10), U8.16 (SI)
SPI0_SCK: U1.38 (GPIO11), U8.14 (SCK)
TX_can: U8.1 (TXCAN), U9.1 (D)
btn_L1: C27.1, R16.1, U1.45 (GPIO24)
btn_L2: C29.1, R20.1, U1.26 (GPIO19)
btn_L3: C31.1, R25.1, U1.30 (GPIO6)
btn_R1: C26.1, R15.1, U1.58 (GPIO2)
btn_R2: C28.1, R19.1, U1.54 (GPIO4)
btn_R3: C30.1, R24.1, U1.48 (GPIO27)
dispBL_PWM: J2.5, U1.49 (GPIO18), U6.3 (D0-)
dispBL_en: J2.4, U1.47 (GPIO23), U6.1 (D0+)
ext_USBD+: J3.A6 (D+), J3.B6 (D+), U1.105 (USB_P), U7.2 (D-)
ext_USBD-: J3.A7 (D-), J3.B7 (D-), U1.103 (USB_N), U7.1 (D+)
nRPIBOOT: SW1.1, U1.93 (~RPIBOOT)

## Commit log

2025-05-07 Rev0 PCB files
    Upload initial issue PCB files; TBD some 3d model files in the user lib are too large to web upload
    [1050570001.stp, AP64501SP-13.step, B3F-5050.STEP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]
2025-05-22 removed old gerbers
    [py_dash_pcb_7-B_Cu.gbr, py_dash_pcb_7-B_Mask.gbr, py_dash_pcb_7-B_Paste.gbr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]
2025-05-22 r1a upload
    uploaded files for r1a; correct button numbering
    [perif.kicad_sch, py_dash_pcb_7.kicad_pcb, py_dash_pcb_7.kicad_sch]
2026-02-16 Rev2a initial upload
    non-PCB files
2026-02-16 Rev2a initial upload
    PCB files
    [BOM_7in_Dash.csv, ext_cons.kicad_sch, perif.kicad_sch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]
2026-02-16 Rev2.0a initial upload
    user lib files
    [CSD23280F3.step, LM66100DCKR.step, TF13BSA-20S-0.4SH_800_.step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]
2026-03-08 push from desktop to align files
    [M2.5_2mm_standoff.STEP, M2.5_3mm_standoff.STEP, M2.5_5mm_standoff.SLDPRT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]
2026-03-10 resolved tracker TODOs
    Updated USBC placement to work with enclosure. Updated HDMI routes with chosen stackup to meet design requirements. Re-generated PCB fab files.
    [12mm_keycap.SLDPRT, B3F-5050(2).SLDASM, B3F-5050.SLDASM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]
2026-03-17 final BOM and tweaking
    Tweaked some dimensions after mechanical assembly. Generated BOM and reviewed against reseller inventory
    [BOM_7in_Dash.csv, M2.5_6mm_standoff.STEP, ext_cons.kicad_sch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]
2026-04-04 updated gerbers for rev2.0a testing manufacture order
    [py_dash_pcb_7-B_Cu.gbr, py_dash_pcb_7-B_Mask.gbr, py_dash_pcb_7-B_Paste.gbr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]
2026-09-12 Updated BOM
2026-09-13 testing updates
    D2, D3 part update, PROG direction on boot switch, removed ribbon cable. updated BOM to reflect changes, re-generated gerbers for slight tweaks
2026-10-13 BOM update
    part number corrections
